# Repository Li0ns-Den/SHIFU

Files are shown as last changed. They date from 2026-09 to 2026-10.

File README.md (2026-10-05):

# SHIFU: Sensing Heat & Intense Fluid Uh-ohs
Data acquisition system for combined fluid temperature and pressure 

<p align="center">
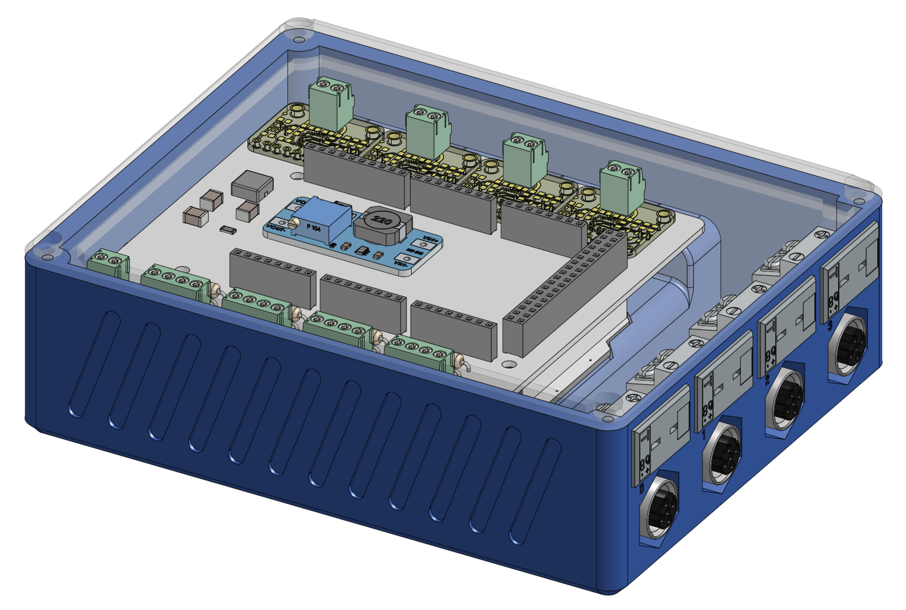
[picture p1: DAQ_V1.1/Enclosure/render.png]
  
</p>

<p align="center">
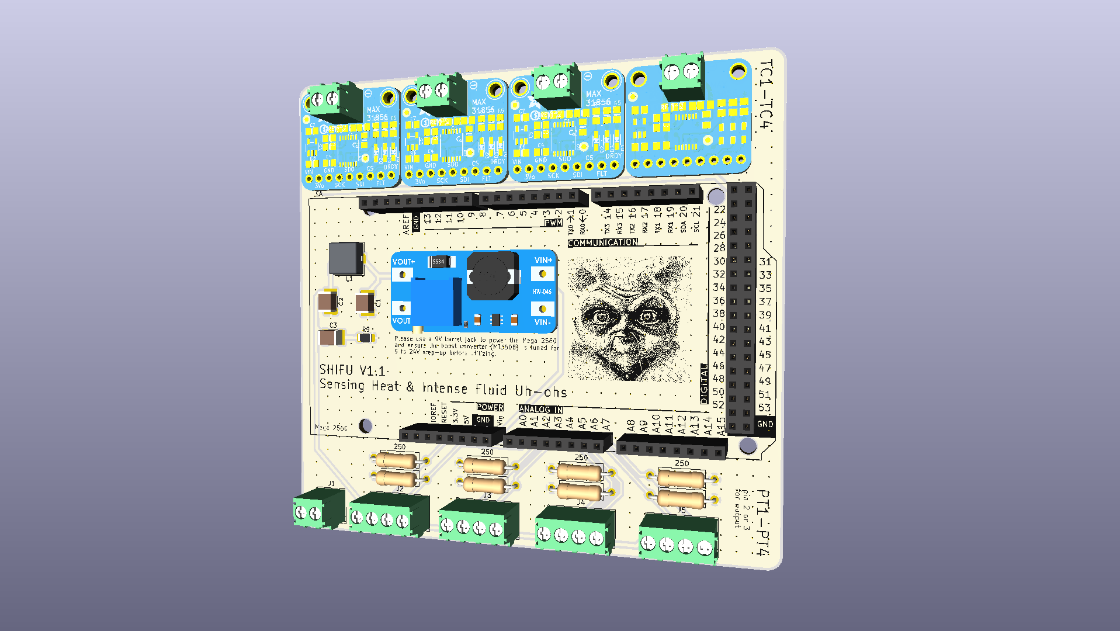
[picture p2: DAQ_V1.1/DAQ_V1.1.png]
  
</p>

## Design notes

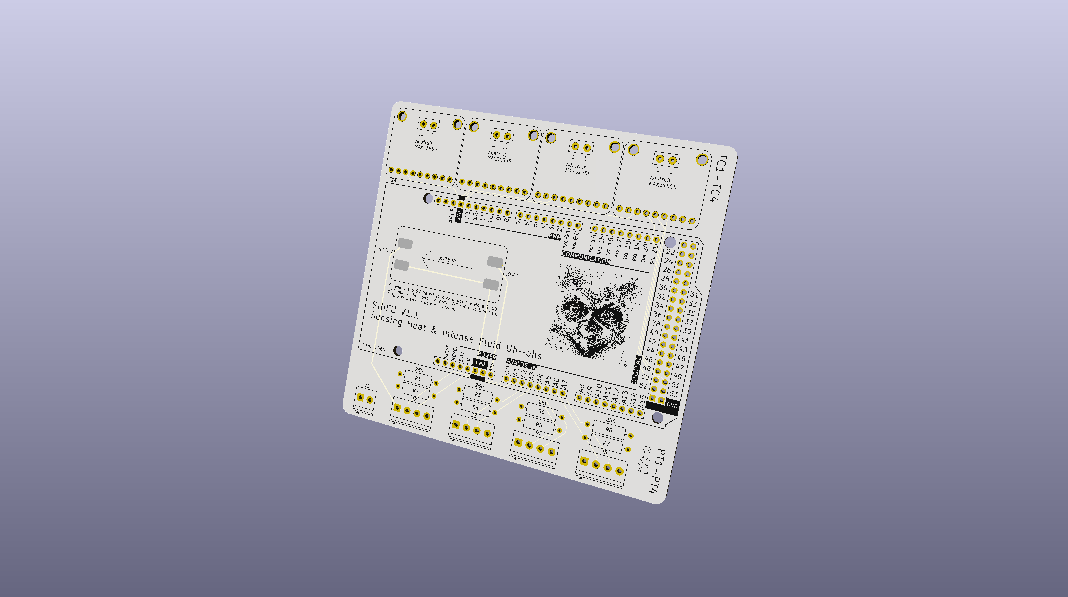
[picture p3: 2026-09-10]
DAQ_V1.1/DAQ_V1.1_bare.png

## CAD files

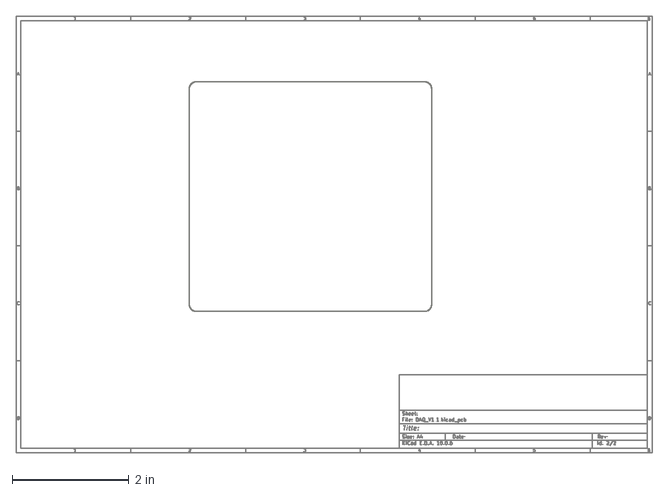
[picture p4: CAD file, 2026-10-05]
DAQ_V1.1/DAQ_V1.1-Edge_Cuts.dxf
10.9 x 7.48 in

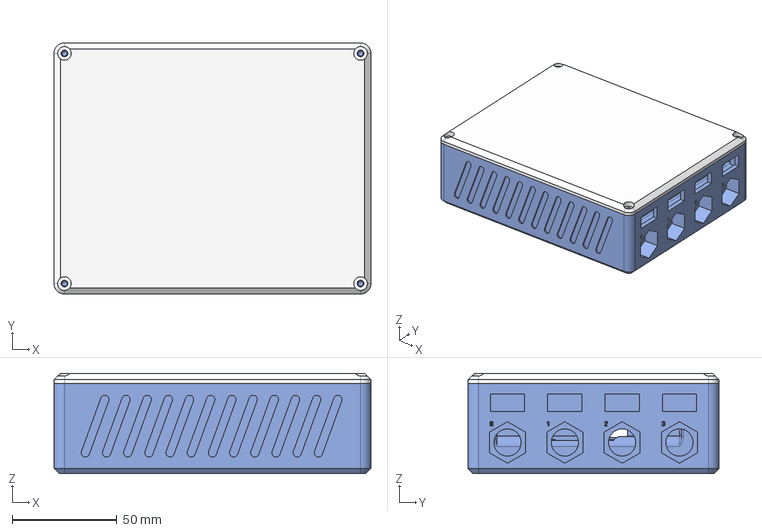
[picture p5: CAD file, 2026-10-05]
DAQ_V1.1/Enclosure/SFU-ENCLS.step
151.5 x 120.0 x 48.0 mm

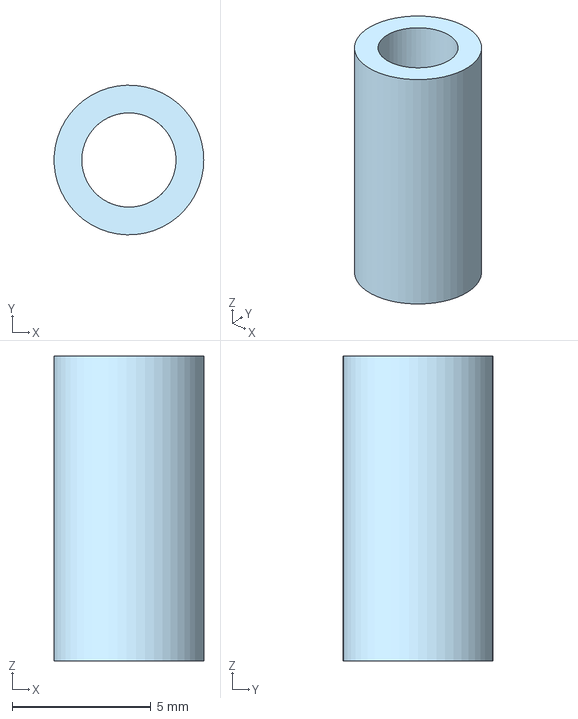
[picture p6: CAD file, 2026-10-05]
DAQ_V1.1/Enclosure/SFU-M3STO.step
5.39 x 5.40 x 11.0 mm

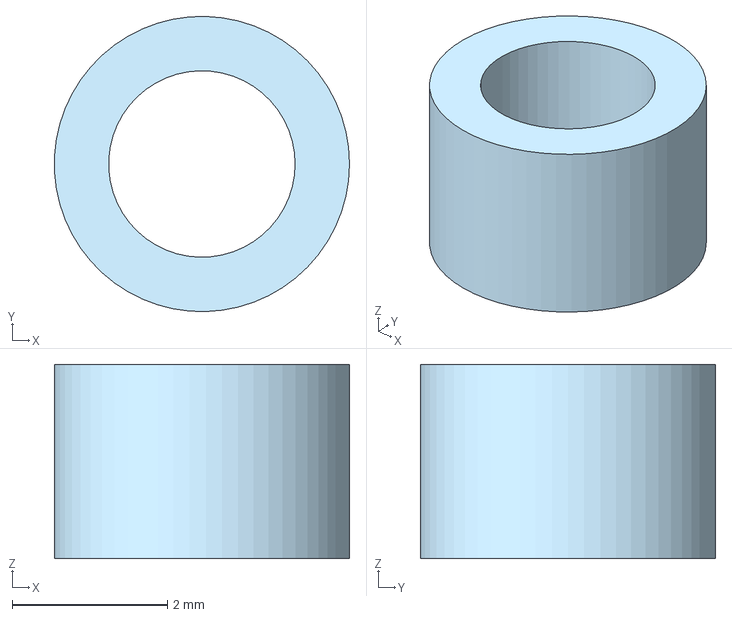
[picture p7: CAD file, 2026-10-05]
DAQ_V1.1/Enclosure/SFU-M2STO.step
3.80 x 3.80 x 2.50 mm

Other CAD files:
DAQ_V1.1/Enclosure/SFU-M2STO.3mf

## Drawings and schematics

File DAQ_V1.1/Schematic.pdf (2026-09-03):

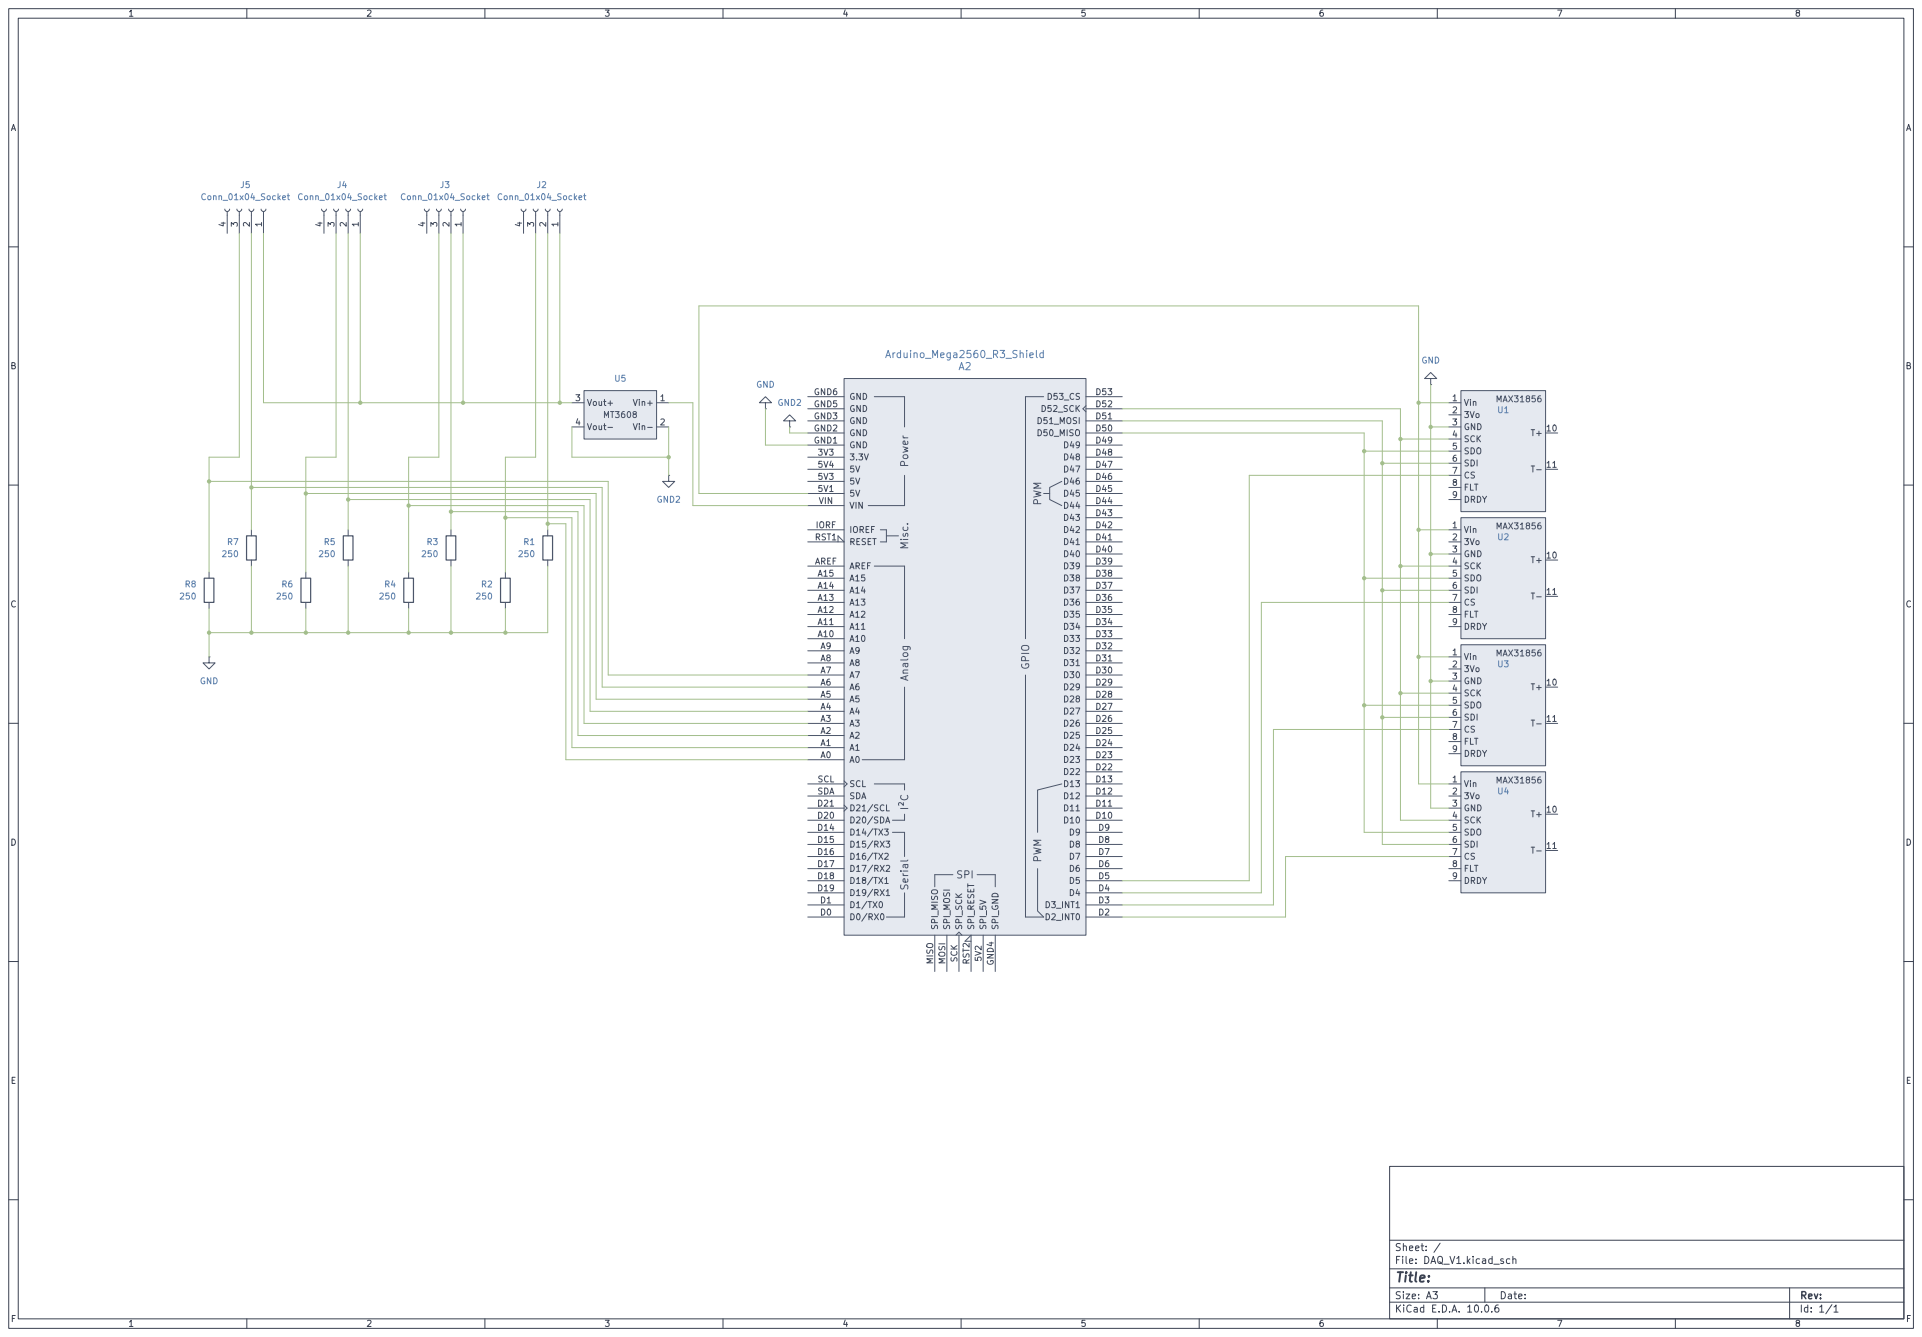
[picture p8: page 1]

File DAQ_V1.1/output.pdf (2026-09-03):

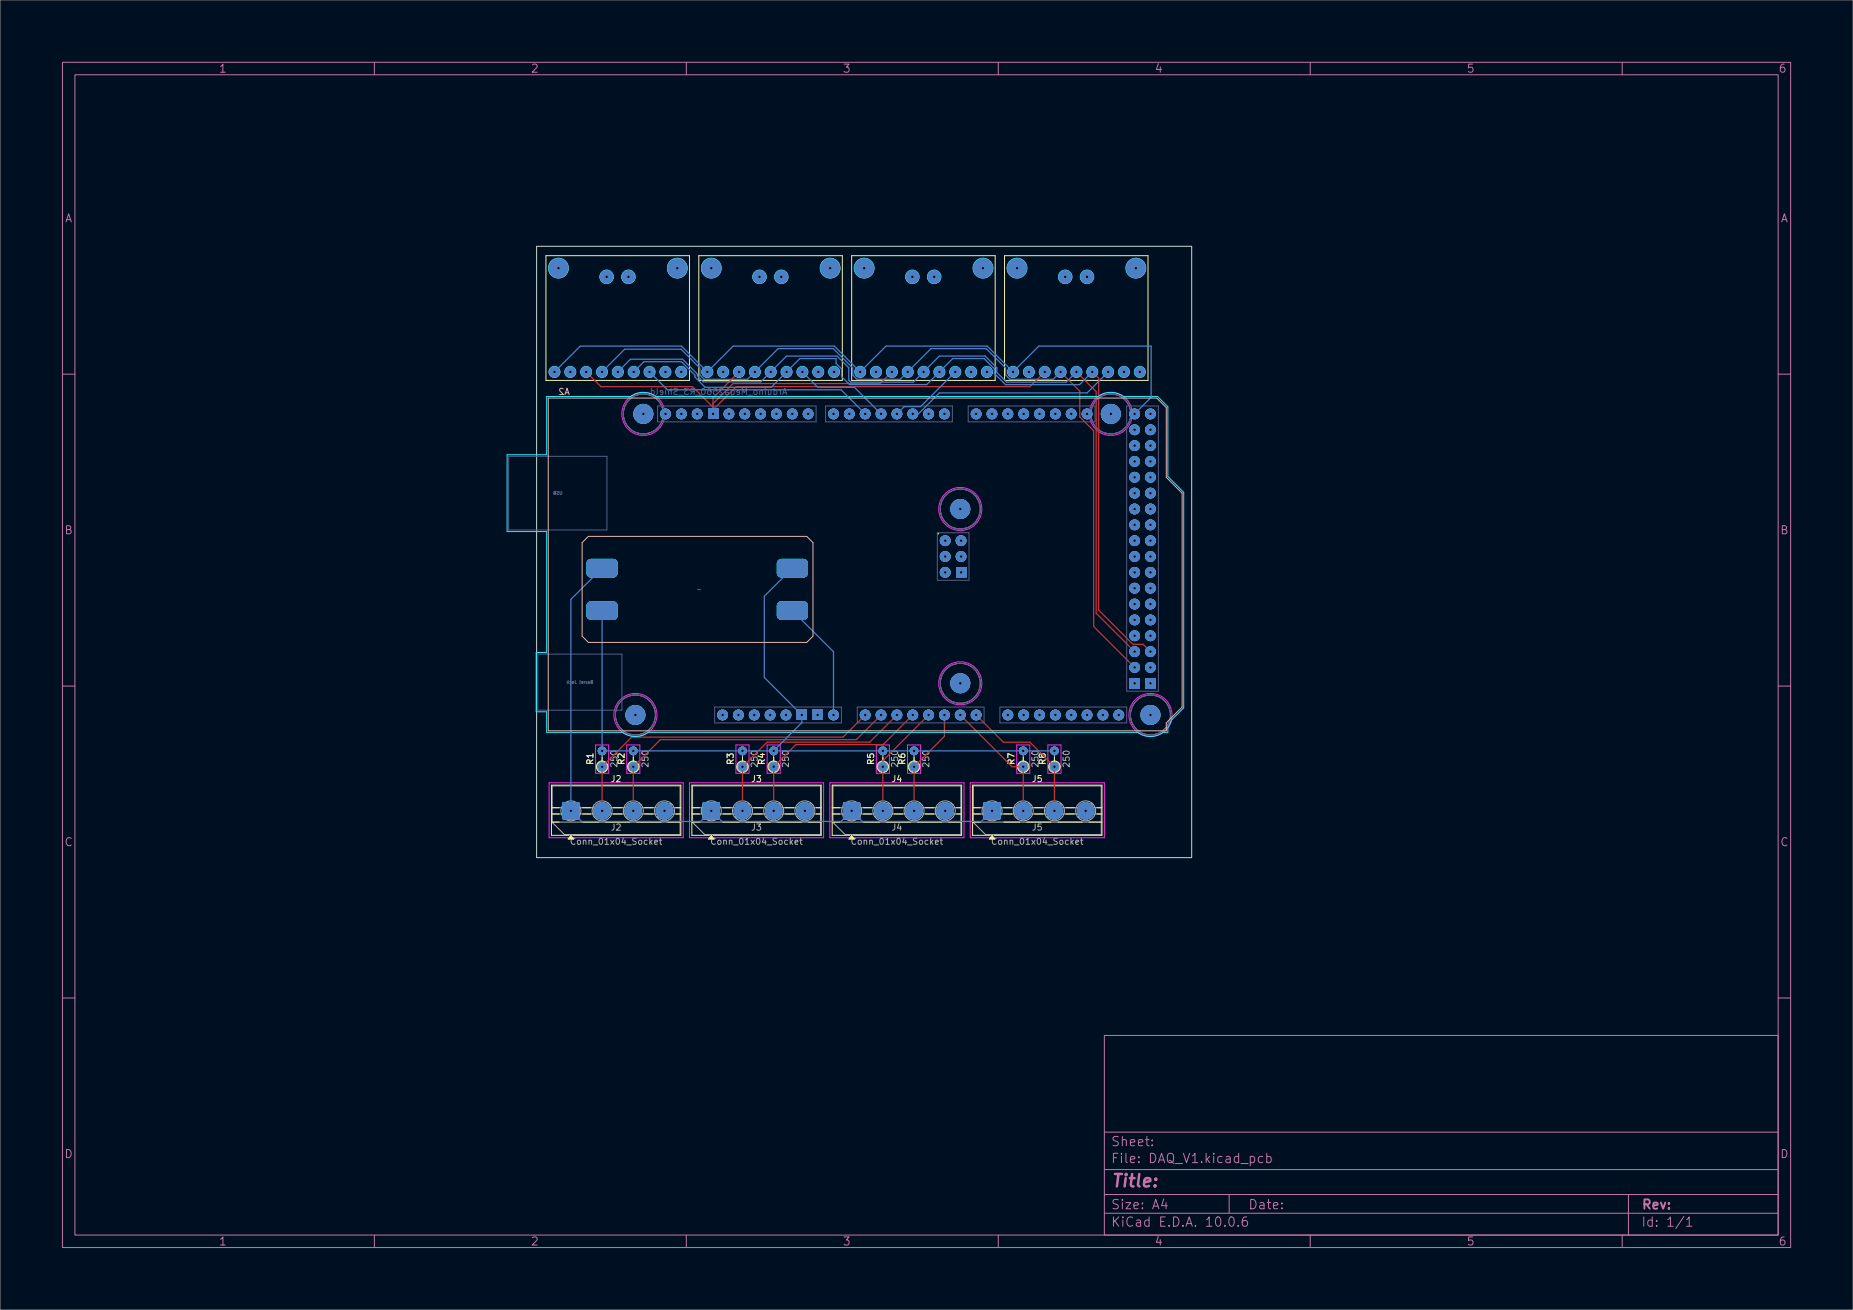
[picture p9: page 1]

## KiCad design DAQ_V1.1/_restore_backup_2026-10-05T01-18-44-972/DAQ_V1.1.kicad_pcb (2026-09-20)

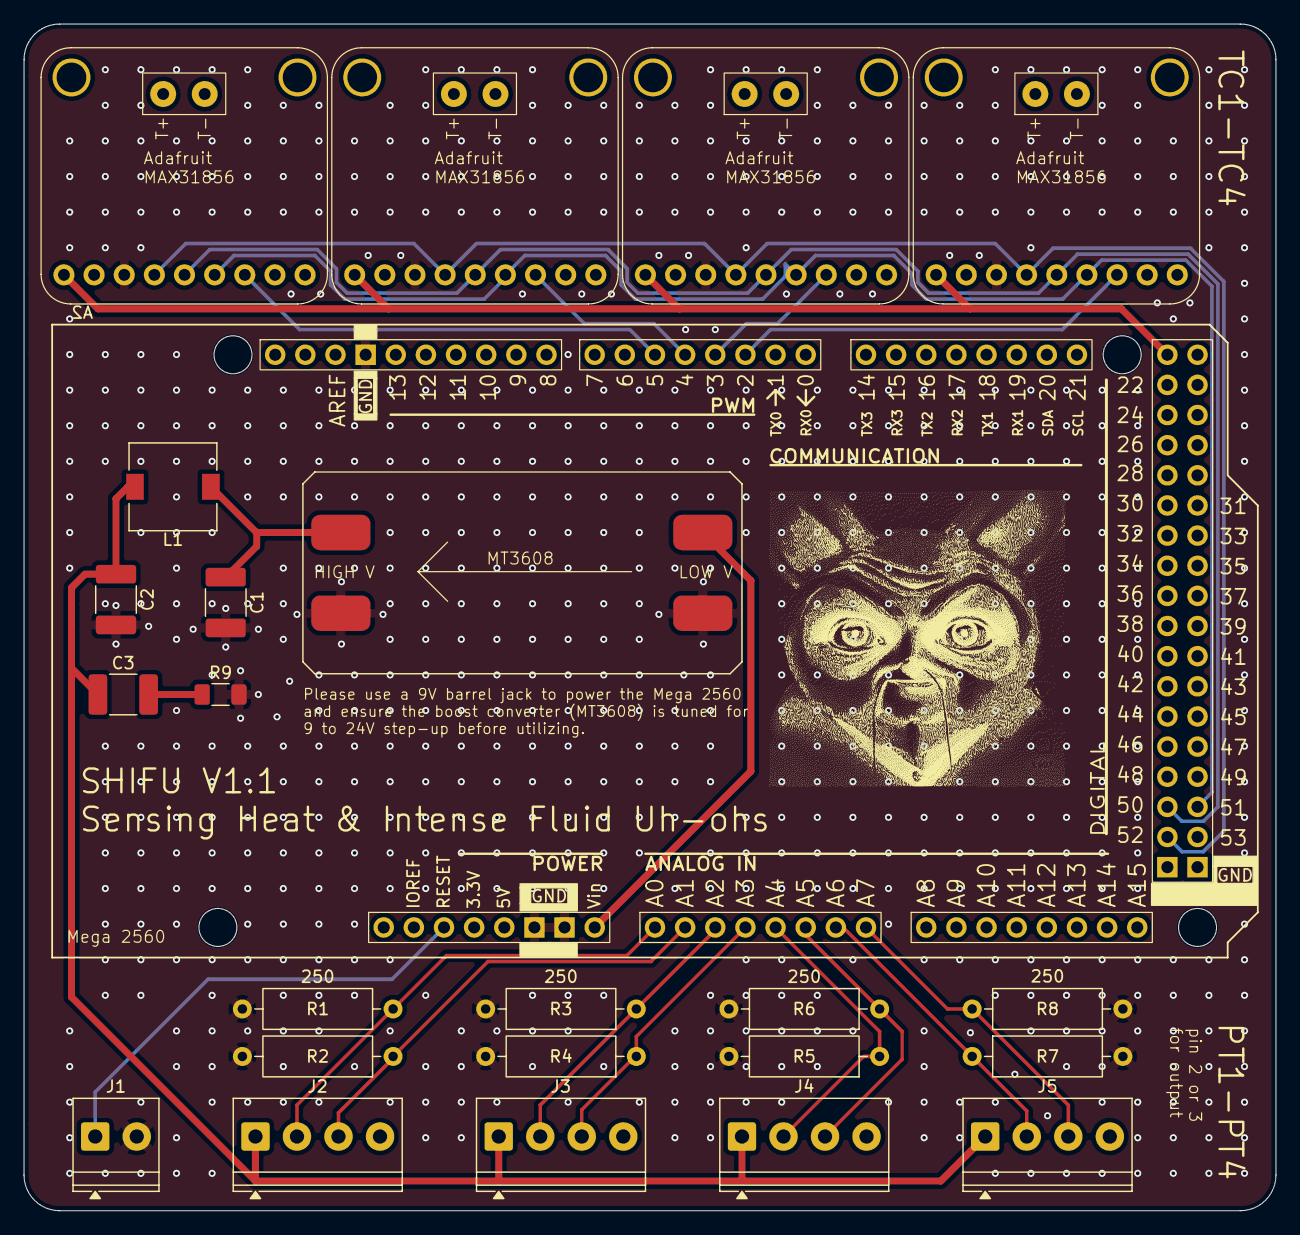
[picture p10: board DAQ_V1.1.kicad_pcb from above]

Board: 4 copper layers, 105.5 x 100.0 mm, 24 parts (0 on the bottom side), 22 nets.

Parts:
A2: Arduino_Mega2560_R3_Shield; Arduino_Mega2560_R3_Shield_custom
C1: 22u; C_1812_4532Metric_Pad1.57x3.40mm_HandSolder
C2: 10u; C_1812_4532Metric_Pad1.57x3.40mm_HandSolder
C3: 47u; C_1812_4532Metric_Pad1.57x3.40mm_HandSolder
J1: Screw_Terminal_01x02; TerminalBlock_Phoenix_PT-1,5-2-3.5-H_1x02_P3.50mm_Horizontal
J2, J3, J4, J5: Screw_Terminal_01x04; TerminalBlock_Phoenix_PT-1,5-4-3.5-H_1x04_P3.50mm_Horizontal
L1: 10u; L_7.3x7.3_H3.5
R1, R2, R3, R4, R5, R6, R7, R8: 250; R_Axial_DIN0309_L9.0mm_D3.2mm_P12.70mm_Horizontal
R9: R; R_1206_3216Metric_Pad1.30x1.75mm_HandSolder
U1, U2, U3, U4: Max31856Pads
U5: hw-045

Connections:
GND: A2.GND1 (GND), A2.GND2 (GND), A2.GND3 (GND), C1.2, C2.2, J1.2, R1.2, R2.2, R3.2, R4.2, R5.2, R6.2, R7.2, R8.2, R9.2, U1.3 (GND), U2.3 (GND), U3.3 (GND), U4.3 (GND), U5.2 (Vin-), U5.4 (Vout-)
unnamed: A2.D2 (D2_INT0), U4.7 (CS)
unnamed: A2.D3 (D3_INT1), U3.7 (CS)
unnamed: A2.D50 (D50_MISO), U1.5 (SDO), U2.5 (SDO), U3.5 (SDO), U4.5 (SDO)
unnamed: A2.D51 (D51_MOSI), U1.6 (SDI), U2.6 (SDI), U3.6 (SDI), U4.6 (SDI)
unnamed: A2.D52 (D52_SCK), U1.4 (SCK), U2.4 (SCK), U3.4 (SCK), U4.4 (SCK)
unnamed: A2.RST1 (RESET), J1.1
unnamed: C3.2, R9.1
unnamed: C2.1, C3.1, J2.1, J3.1, J4.1, J5.1, L1.2
unnamed: A2.A0, J2.2, R1.1
unnamed: A2.A1, J2.3, R2.1
unnamed: A2.A2, J3.2, R3.1
unnamed: A2.A3, J3.3, R4.1
unnamed: A2.A4, J4.2, R5.1
unnamed: A2.A5, J4.3, R6.1
unnamed: A2.A6, J5.2, R7.1
unnamed: A2.A7, J5.3, R8.1
unnamed: A2.D5, U1.7 (CS)
unnamed: A2.5V3 (5V), U1.1 (Vin), U2.1 (Vin), U3.1 (Vin), U4.1 (Vin)
unnamed: A2.D4, U2.7 (CS)
unnamed: A2.VIN, U5.1 (Vin+)
unnamed: C1.1, L1.1, U5.3 (Vout+)

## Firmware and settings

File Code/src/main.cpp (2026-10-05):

#include "HardwareSerial.h"
#include "pins_arduino.h"
#include <Arduino.h>
#include <Adafruit_MAX31856.h>
#include <SPI.h>

const int CS_PINS[] = {2,3,4,5};
const int NUM_SENSORS = 4;

String tcTypesStr[NUM_SENSORS] = {"K", "K", "K", "T"};

unsigned long startTime = 0;
int ptVal[8];
float tcVal[4];

Adafruit_MAX31856 maxChips[] = {
  Adafruit_MAX31856(CS_PINS[0]),
  Adafruit_MAX31856(CS_PINS[1]),
  Adafruit_MAX31856(CS_PINS[2]),
  Adafruit_MAX31856(CS_PINS[3])
};

max31856_thermocoupletype_t getTypeFromString(String typeStr) {
  typeStr.toUpperCase();
  typeStr.trim();
  
  if (typeStr == "B") return MAX31856_TCTYPE_B;
  if (typeStr == "E") return MAX31856_TCTYPE_E;
  if (typeStr == "J") return MAX31856_TCTYPE_J;
  if (typeStr == "K") return MAX31856_TCTYPE_K;
  if (typeStr == "N") return MAX31856_TCTYPE_N;
  if (typeStr == "R") return MAX31856_TCTYPE_R;
  if (typeStr == "S") return MAX31856_TCTYPE_S;
  if (typeStr == "T") return MAX31856_TCTYPE_T;
  
  return MAX31856_TCTYPE_K; // Default fallback if string is invalid
}

void setup() {
  // initializing
  Serial.begin(115200);

  // initializing thermocouples
  for (int i = 0; i < NUM_SENSORS; i++) {
    if (!maxChips[i].begin()) {
    Serial.println("Could not initialize thermocouple " + String(i));
    while (1) delay(10);
    }
    else {
    // Serial.println("Initialized Sensor " + String(i));
    // Set thermocouple type (e.g., K-type)
    max31856_thermocoupletype_t currentType = getTypeFromString(tcTypesStr[i]);
    maxChips[i].setThermocoupleType(currentType);
    maxChips[i].setConversionMode(MAX31856_CONTINUOUS); 
    }
  }
  
  Serial.println("Controller initialized, press enter to continue");

  while (Serial.available() == 0) {}  // waiting

  while (Serial.available() > 0) {
    Serial.read();
  }
  startTime = millis();
  // Serial.println("STARTING");
}

void loop() {
  // assiging relative time to recording start
  unsigned long relTime = millis() - startTime;
  Serial.print(relTime);
  // Serial.print(",");
  // Read the analog pins
  for (int i = 0; i < 8; i++) {
    ptVal[i] = analogRead(A0 + i);
    Serial.print(",");
    Serial.print(ptVal[i]);
  }

  for (int i = 0; i < 4; i++) {
    tcVal[i] = maxChips[i].readThermocoupleTemperature();
    Serial.print(",");
    Serial.print(tcVal[i]);
  }

  Serial.println();
    
  delay(1);
}

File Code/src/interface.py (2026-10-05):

import serial
import serial.tools.list_ports
import csv
import sys
import time
import datetime
import readline
import math
from collections import deque

def input_with_preset(prompt, preset):
    readline.set_startup_hook(lambda: readline.insert_text(preset))
    try:
        return input(prompt)
    finally:
        readline.set_startup_hook()

def hard_reset_mega(ser):
    print("Sending hard reset command to Mega...")
    # Drop DTR line to trigger hardware reset
    ser.dtr = False
    time.sleep(0.1)
    
    # Bring it back up to let the board boot up normally
    ser.dtr = True
    time.sleep(1.0) # Give the Mega a second to run its setup() routine
    # print("Mega successfully restarted!")

def list_active_ports():
    # Fetch all available serial ports\
    default = None
    ports = serial.tools.list_ports.comports()
    
    if not ports:
        print("No connected serial devices found.")
        return

    print("Connected Serial Ports:")
    print("-" * 80)

    for port in ports:
        # port.device is the name (e.g., COM3 or /dev/ttyUSB0)
        # port.description is the device name given by the OS
        if port.hwid != 'n/a':
            print(f"Port: {port.device}")
            print(f"Description: {port.description}")
            print(f"Hardware ID: {port.hwid}")
            print("-" * 80)
            if default is None:
                default = port.device

    return default

print("")
print('=' * 80)
print("""                        ____  _   _  _____ ______ _   _ 
                      /  ___|| | | ||_   _||  ___| | | |
                      \ `--. | |_| |  | |  | |_  | | | |
                       `--. \|  _  |  | |  |  _| | | | |
                      /\__/ /| | | |__| |__| |_  | |_| |
                      \____(_)_| |_(_)___(_)_(_)  \___/      
""")
print('=' * 80)
print("                  SHIFU - Sensing Heat & Intense Fluid Uh-ohs                   ")
print('-' * 80)
print('***                     GNU General Public License 2.0                       ***')
print('=' * 80)
# listing active ports
default_dev = list_active_ports()
default_baud = 115200
default_name = f'output_{str(datetime.datetime.now().strftime("%Y%m%d_%H%M%S"))}.csv'

if default_dev == None:
    print('No avaliable serial devices found: Exiting SHIFU')
    sys.exit()

PORT = input_with_preset("Enter port name: ", f'{default_dev}')
BAUD = input_with_preset("Enter baud rate: ", f'{default_baud}')
filename = input_with_preset("Enter log file name: ", f'{default_name}')

# Pressure transducer mapping
Amax = 20e-3
Amin = 4e-3
# Setting calibrating resistor values for PT0 - PT7
R = [250.0, 250.0, 250.0, 250.0, 250.0, 250.0, 250.0, 250.0]
# Setting pressure ranges on PT0 - PT7
Pmax = [250.0, 40.0, 1.0, 1.0, 1.0, 1.0, 1.0, 1.0]
Pmin = [0.0, 0.0, 0.0, 0.0, 0.0, 0.0, 0.0, 0.0]

Vmax = [Amax * r for r in R]
Vmin = [Amin * r for r in R]

rollingSample = 100

rollingP = [deque(maxlen=rollingSample) for _ in range(8)]
P_avg = [0.0] * 8

ser = serial.Serial(PORT, BAUD, timeout = 1)
print(f'Listening on {PORT}')

try:
    line = ser.readline().decode('utf-8').strip()   
    print(line)

    ser.write((input() + "\n").encode("utf-8"))
    ser.flush()
    with open(filename, 'a', newline='') as csv_file:
        csv_writer = csv.writer(csv_file)

        pt_headers = []
        for i in range(4):
            pt_headers.append(f"PT{i+1}_A")
            pt_headers.append(f"PT{i+1}_B")

        tc_headers = [f"TC{i+1}" for i in range(4)]
        headers = ["timestamp", "elapsed(s)"] + pt_headers + tc_headers
        
        csv_writer.writerow(headers)
        csv_file.flush()
        print(f"Logging started. Writing directly to {filename}")

        while True:

            if ser.in_waiting > 0: 
                decoded_line = ser.readline().decode('utf_8').strip()
                if decoded_line:
                    try:
                        data_fields = decoded_line.split(',')

                        if len(data_fields) >= 13:

                            if len(data_fields) >= 9:
                                relTime = int(data_fields[0])
                                seconds = relTime / 1000

                                ptVal = [int(val) for val in data_fields[1:9]]
                                volt = [float(val) * 5.0 / 1023.0 for val in ptVal]
                                pressure = [Pmin + (v - Vmin) * ((Pmax - Pmin) / (Vmax - Vmin)) for v, Vmin, Vmax, Pmin, Pmax in zip(volt, Vmin, Vmax, Pmin, Pmax)]
                                
                                for i in range(8):

                                    rollingP[i].append(pressure[i])
                                    P_avg[i] = sum(rollingP[i]) / len(rollingP[i])

                            tcVal = [float(val) for val in data_fields[9:13]]
                            temperature = tcVal

                            cal_time = datetime.datetime.now().strftime("%d/%m/%Y %H:%M")

                            row = [cal_time, seconds] + pressure + temperature
                            csv_writer.writerow(row)
                            csv_file.flush()

                            # Map raw indices (0, 2, 4, 6) to PT0_A through PT3_A
                            pt_string_A = " | ".join(f"PT{i+1} A: {P_avg[i*2]:.1f}" for i in range(4))
                            
                            # Map raw indices (1, 3, 5, 7) to PT0_B through PT3_B
                            pt_string_B = " | ".join(f"PT{i+1} B: {P_avg[i*2+1]:.1f}" for i in range(4))

                            tc_string = " | ".join(f"TC{i+1}: {t:.1f}°C" for i, t in enumerate(temperature))

                            dashboard = (
                                f"\033[H"                            
                                f"SHIFU TELEMETRY SYSTEM\033[K\n"  
                                f"{'-' * 80}\033[K\n"                
                                f"Time:     | {seconds:.2f}s\033[K\n"
                                f"Pressure: | {pt_string_A}\033[K\n"
                                f"          | {pt_string_B}\033[K\n"   
                                f"Temp:     | {tc_string}\033[K\n"    
                                f"{'-' * 80}\033[K\n"        
                                f"\033[J"                            
                            )
                            print(dashboard, end="", flush=True)

                    except (ValueError, IndexError, UnicodeDecodeError):
                        continue

except KeyboardInterrupt:
    print("\nStopping...")
    ser.write
finally:
    hard_reset_mega(ser)
    ser.close()

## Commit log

2026-09-03 Included Schematics + PCB for V1
    [DAQ_V1-B_Cu.gbr, DAQ_V1-B_Mask.gbr, DAQ_V1-B_Paste.gbr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]
2026-09-03 Updated PCB design
    [DAQ_V1.kicad_pcb, DAQ_V1.kicad_sch]
2026-09-04 V1.1 Updated design for bottom arduino mounting
    [DAQ_V1.1-B_Cu.gbr, DAQ_V1.1-B_Mask.gbr, DAQ_V1.1-B_Paste.gbr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]
2026-09-07 Added PT firmware and logging interface
    [DAQ_V1.1.kicad_pcb, DAQ_V1.1.kicad_sch]
2026-09-10 Rework to firmware, interface + minor changes to PCB
    [DAQ_V1.1.kicad_pcb, DAQ_V1.1.kicad_sch]
2026-09-15 Added Control on individual sensor inputs
2026-09-20 Major changes to SHIFU PCB - Changed to 4 layer - Added Ground Planes - Filled Zones - Pi filter integration
    [DAQ_V1.1.kicad_pcb, DAQ_V1.1.kicad_sch]
2026-10-05 Complete system of SHIFU 1.1
    [DAQ_V1.1-Edge_Cuts.dxf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]
2026-10-05 Added renders to README
    [DAQ_V1.1.kicad_pcb, DAQ_V1.1.kicad_sch]
